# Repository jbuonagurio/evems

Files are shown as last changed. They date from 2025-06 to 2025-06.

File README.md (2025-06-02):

# Power Quality Analyzer

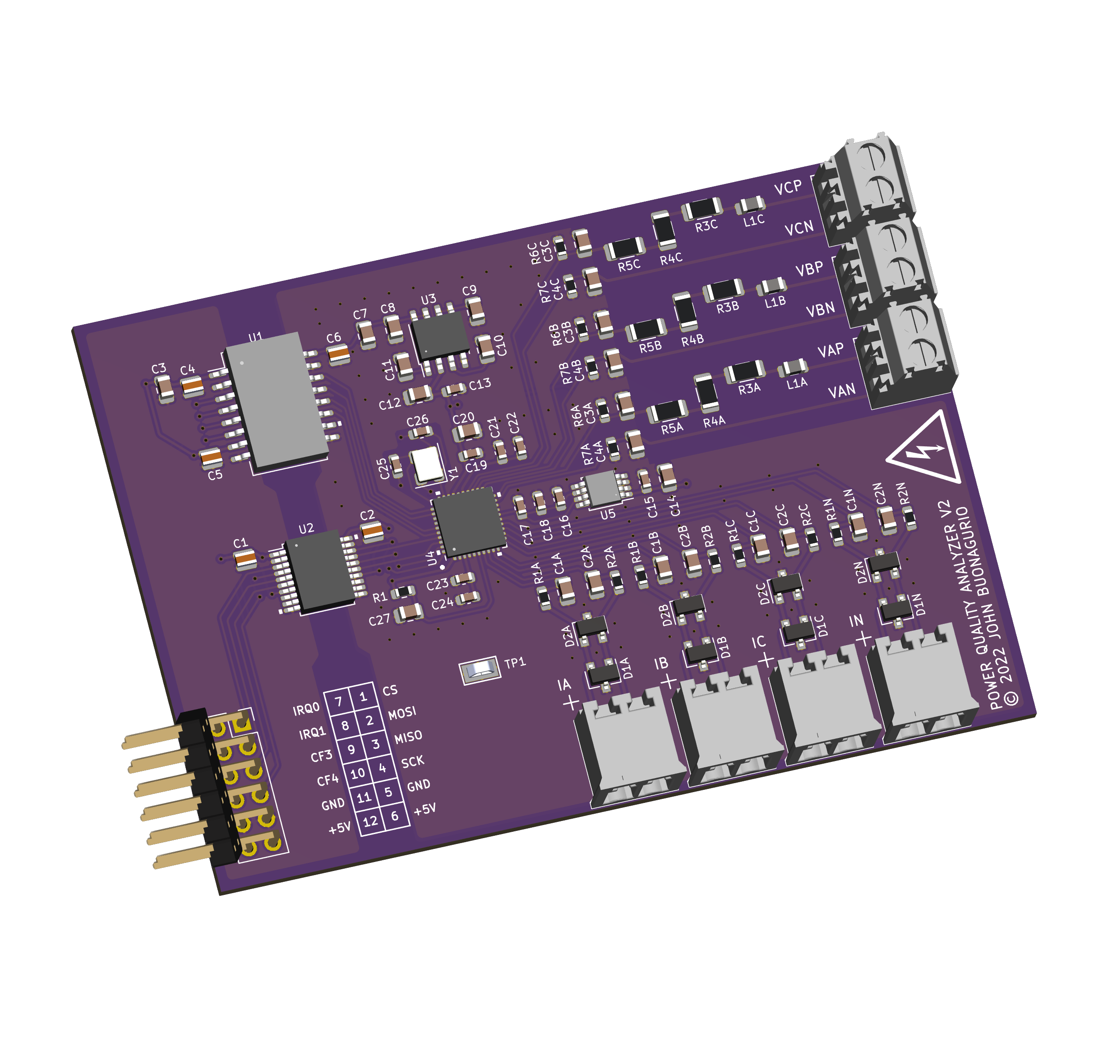
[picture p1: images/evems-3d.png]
3D View


## Schematic

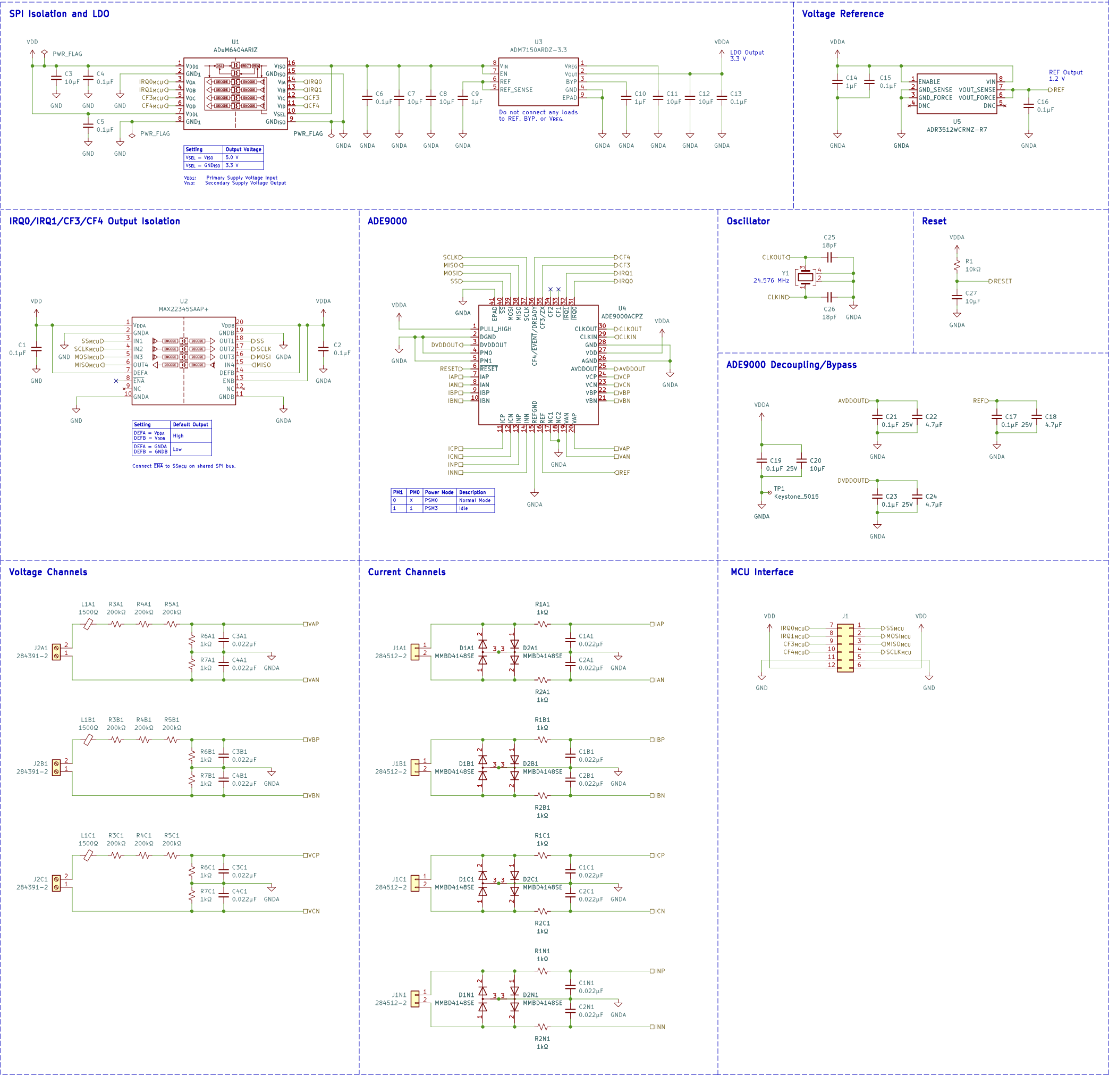
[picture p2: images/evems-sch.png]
Schematic


## Bill of Materials

| Designator | Quantity | Description | Manufacturer | Manufacturer Part Number | Digi-Key Part Number |
| :--- | :---: | :--- | :--- | :--- | :--- |
| C1 C2 C4 C5 C6 | 5 | Ceramic Capacitor 0.1 μF 25V X7R 0508 | KYOCERA AVX | 05083C104KAT2A | 478-12665-1-ND |
| C9 C10 C14 | 3 | Ceramic Capacitor 1 μF 35V X7R 0805 | KEMET | C0805C105K6RACTU | 399-15007-1-ND |
| C13 C15 C16 | 3 | Ceramic Capacitor 0.1 μF 10V X7R 0603 | KEMET | C0603C104K8RACTU | 399-C0603C104K8RAC7867CT-ND |
| C17 C19 C21 C23 | 4 | Ceramic Capacitor 0.1 μF 25V X8R 0603 | TDK Corporation | C1608X8R1E104K080AA | 445-2500-1-ND |
| C3 C7 C8 C11 C12  C20 C27 | 7 | Ceramic Capacitor 10 μF 25V X5R 0805 | KEMET | C0805C106K3PACTU | 399-11939-1-ND |
| C18 C22 C24 | 3 | Ceramic Capacitor 4.7 μF 10V X5R 0603 | KEMET | C0603C475K8PACTU | 399-C0603C475K8PAC7411CT-ND |
| C25 C26 | 2 | Ceramic Capacitor 18 pF 50V NP0 0603 | KEMET | CBR06C180J5GAC | 399-CBR06C180J5GACCT-ND |
| C1A C1B C1C C1N C2A  C2B C2C C2N C3A C3B C3C C4A C4B C4C | 14 | Ceramic Capacitor 0.022 μF 50V C0G 0805 | TDK Corporation | C2012C0G1H223J125AA | 445-7522-1-ND |
| D1A D1B D1C D1N D2A  D2B D2C D2N | 8 | Dual Switching Diode 100V 300mA SOT23 | Diodes Inc. | MMBD7000HS-7-F | MMBD7000HS-7FDICT-ND |
| J1 | 1 | Header 12 Position 0.100" (2.54mm) RA Through Hole | Samtec Inc. | TSW-106-08-L-D-RA | SAM1041-06-ND |
| J1A J1B J1C J1N | 4 | 2 Position Terminal Block 0.138" (3.50mm) RA Through Hole | TE Connectivity | 284512-2 | A98396-ND |
| J2A J2B J2C | 3 | 2 Position Terminal Block 0.138" (3.50mm) RA Through Hole | TE Connectivity | 284391-2 | A98159-ND |
| L1A L1B L1C | 3 | Ferrite Bead 1.5 kΩ @ 100 MHz 0805 250mA 450mΩ | Murata | BLM21BD152SN1D | 490-1048-1-ND |
| R1 | 1 | Resistor 10 kΩ ±1% 0.1W 0603 | Vishay Dale | CRCW060310K0FKEAC | 541-5136-1-ND |
| R1A R1B R1C R1N R2A  R2B R2C R2N R6A R6B R6C R7A R7B R7C | 14 | Resistor 1 kΩ ±0.1% 0.1W 0603 Thin Film | YAGEO | RT0603BRD071KL | YAG1237CT-ND |
| R3A R3B R3C R4A R4B  R4C R5A R5B R5C | 9 | Resistor 200 kΩ ±0.1% 0.25W 1206 Thin Film | Vishay Dale | TNPV1206200KBEEN | 541-4632-1-ND |
| TP1 | 1 | Test Point Miniature | Keystone Electronics | 5015 | 36-5015CT-ND |
| U1 | 1 | Digital Isolator 4 Channel 5000VRMS 16SOIC | Analog Devices Inc.  | ADUM6404ARIZ | 505-ADUM6404ARIZ-ND |
| U2 | 1 | Digital Isolator 4 Channel 3750VRMS 20SSOP | Maxim Integrated | MAX22345SAAP+ | 505-MAX22345SAAP+-ND |
| U3 | 1 | Linear Voltage Regulator 3.3V 800mA 8-SOIC-EP | Analog Devices Inc.  | ADM7150ARDZ-3.3 | 505-ADM7150ARDZ-3.3-ND |
| U4 | 1 | 7 Channel AFE 40-LFCSP-WQ | Analog Devices Inc.  | ADE9000ACPZ | 505-ADE9000ACPZ-ND |
| U5 | 1 | Voltage Reference 1.2V ±0.1% 10mA 8-MSOP | Analog Devices Inc.  | ADR3512WCRMZ-R7 | ADR3512WCRMZ-R7CT-ND |
| Y1 | 1 | Crystal 24.576 MHz ±20ppm 12pF 40Ω 4-SMD | ECS | ECS-245.7-12-33Q-JES-TR  | XC2178CT-ND |

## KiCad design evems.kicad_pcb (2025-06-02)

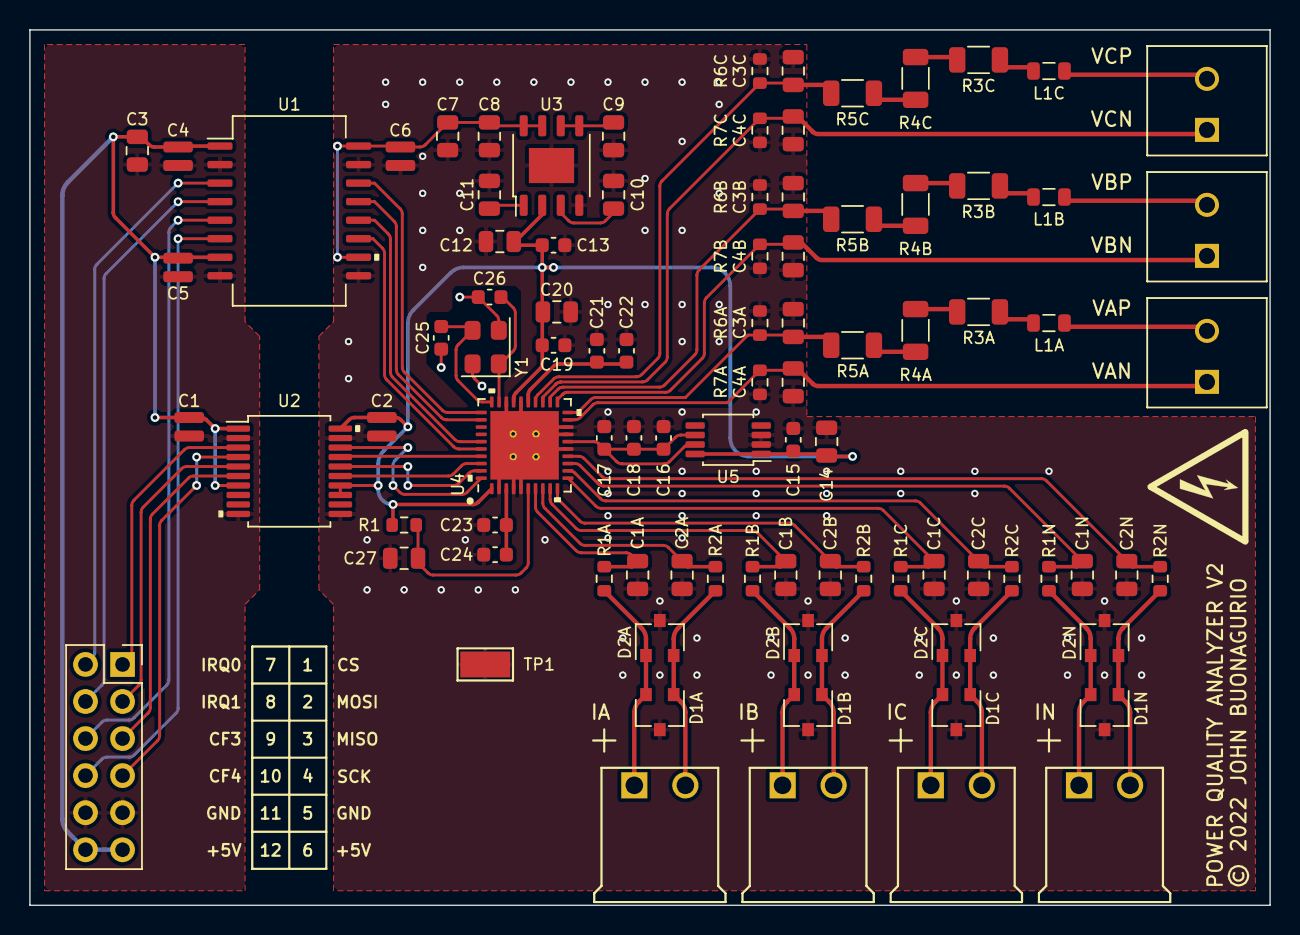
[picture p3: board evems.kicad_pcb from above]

Board: 2 copper layers, 85.0 x 60.0 mm, 91 parts (0 on the bottom side), 64 nets.

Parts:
C1, C2, C4, C5, C6: 0.1µF; C_0508_1220Metric
C1A1, C1B1, C1C1, C1N1, C2A1, C2B1, C2C1, C2N1, C3A1, C3B1, C3C1, C4A1, C4B1, C4C1: 0.022µF; C_0805_2012Metric
C3, C7, C8, C11, C12, C20, C27: 10µF; C_0805_2012Metric
C9, C10, C14: 1µF; C_0805_2012Metric
C13, C15, C16: 0.1µF; C_0603_1608Metric
C17, C19, C21, C23: 0.1µF 25V; C_0603_1608Metric
C18, C22, C24: 4.7µF; C_0603_1608Metric
C25, C26: 18pF; C_0603_1608Metric
D1A1, D1B1, D1C1, D1N1, D2A1, D2B1, D2C1, D2N1: MMBD4148SE; SC-59
J1: Conn_02x06_Top_Bottom; PinHeader_2x06_Pmod
J1A1, J1B1, J1C1, J1N1: 284512-2; TE_284512-2
J2A1, J2B1, J2C1: 284391-2; TE_284391-2
L1A1, L1B1, L1C1: 1500Ω; L_0805_2012Metric
R1: 10kΩ; R_0603_1608Metric
R1A1, R1B1, R1C1, R1N1, R2A1, R2B1, R2C1, R2N1, R6A1, R6B1, R6C1, R7A1, R7B1, R7C1: 1kΩ; R_0603_1608Metric
R3A1, R3B1, R3C1, R4A1, R4B1, R4C1, R5A1, R5B1, R5C1: 200kΩ; R_1206_3216Metric
TP1: Keystone_5015
U1: ADuM6404ARIZ
U2: MAX22345SAAP+
U3: ADM7150ARDZ-3.3
U4: ADE9000ACPZ
U5: ADR3512WCRMZ-R7
Y1: ECS-245.7-12-33Q-JES-TR

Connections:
/AVDDOUT: C21.1, C22.1, U4.25 (AVDDOUT)
/CF3: U1.12 (V_{IC}), U4.35 (CF3/ZX)
/CF3_{MCU}: J1.9, U1.5 (V_{OC})
/CF4: U1.11 (V_{ID}), U4.36 (CF4/~EVENT/DREADY)
/CF4_{MCU}: J1.10, U1.6 (V_{OD})
/CLKIN: C26.1, U4.29 (CLKIN), Y1.1
/CLKOUT: C25.1, U4.30 (CLKOUT), Y1.3
/DVDDOUT: C23.1, C24.1, U4.3 (DVDDOUT)
/IAN: C2A1.2, R2A1.1, U4.8 (IAN)
/IAP: C1A1.1, R1A1.1, U4.7 (IAP)
/IBN: C2B1.2, R2B1.1, U4.10 (IBN)
/IBP: C1B1.1, R1B1.1, U4.9 (IBP)
/ICN: C2C1.2, R2C1.1, U4.12 (ICN)
/ICP: C1C1.1, R1C1.1, U4.11 (ICP)
/INN: C2N1.2, R2N1.1, U4.14 (INN)
/INP: C1N1.1, R1N1.1, U4.13 (INP)
/IRQ0: U1.14 (V_{IA}), U4.31 (~IRQ0)
/IRQ0_{MCU}: J1.7, U1.3 (V_{OA})
/IRQ1: U1.13 (V_{IB}), U4.32 (~IRQ1)
/IRQ1_{MCU}: J1.8, U1.4 (V_{OB})
/MISO: U2.15 (IN4), U4.38 (MISO)
/MISO_{MCU}: J1.3, U2.6 (OUT4)
/MOSI: U2.16 (OUT3), U4.39 (MOSI)
/MOSI_{MCU}: J1.2, U2.5 (IN3)
/REF: C16.1, C17.1, C18.1, U4.16 (REF), U5.6 (VOUT_FORCE), U5.7 (VOUT_SENSE)
/RESET: C27.1, R1.1, U4.6 (~RESET)
/SCLK: U2.17 (OUT2), U4.37 (SCLK)
/SCLK_{MCU}: J1.4, U2.4 (IN2)
/SS: U2.18 (OUT1), U4.40 (~SS)
/SS_{MCU}: J1.1, U2.3 (IN1)
/VAN: C4A1.2, J2A1.1, R7A1.1, U4.19 (VAN)
/VAP: C3A1.1, R5A1.1, R6A1.2, U4.20 (VAP)
/VBN: C4B1.2, J2B1.1, R7B1.1, U4.21 (VBN)
/VBP: C3B1.1, R5B1.1, R6B1.2, U4.22 (VBP)
/VCN: C4C1.2, J2C1.1, R7C1.1, U4.23 (VCN)
/VCP: C3C1.1, R5C1.1, R6C1.2, U4.24 (VCP)
GND: C1.2, C3.2, C4.2, C5.2, J1.5, J1.11, U1.2 (GND_{1}), U1.8 (GND_{1}), U2.2 (GNDA), U2.10 (GNDA)
GNDA: C1A1.2, C1B1.2, C1C1.2, C1N1.2, C2.2, C2A1.1, C2B1.1, C2C1.1, C2N1.1, C3A1.2, C3B1.2, C3C1.2, C4A1.1, C4B1.1, C4C1.1, C6.2, C7.2, C8.2, C9.2, C10.1, C11.1, C12.1, C13.1, C14.2, C15.2, C16.2, C17.2, C18.2, C19.2, C20.2, C21.2, C22.2, C23.2, C24.2, C25.2, C26.2, C27.2, D1A1.3 (common), D1B1.3 (common), D1C1.3 (common), D1N1.3 (common), D2A1.3 (common), D2B1.3 (common), D2C1.3 (common), D2N1.3 (common), R6A1.1, R6B1.1, R6C1.1, R7A1.2, R7B1.2, R7C1.2, TP1.1, U1.9 (GND_{ISO}), U1.15 (GND_{ISO}), U2.11 (GNDB), U2.19 (GNDB), U3.4 (GND), U3.9 (EPAD), U4.2 (DGND), U4.4 (PM0), U4.5 (PM1), U4.15 (REFGND), U4.17 (NC1), U4.18 (NC2), U4.26 (AGND), U4.28 (GND), U4.41 (EPAD), U5.2 (GND_SENSE), U5.3 (GND_FORCE), Y1.2, Y1.4
unnamed: C6.1, C7.1, C8.1, U1.10 (V_{SEL}), U1.16 (V_{ISO}), U3.7 (EN), U3.8 (V_{IN})
unnamed: C9.1, U3.5 (REF_SENSE), U3.6 (REF)
unnamed: C10.2, U3.3 (BYP)
unnamed: C11.2, U3.1 (V_{REG})
unnamed: D1A1.1 (A), D2A1.2 (K), J1A1.2, R2A1.2
unnamed: D1A1.2 (K), D2A1.1 (A), J1A1.1, R1A1.2
unnamed: D1B1.1 (A), D2B1.2 (K), J1B1.2, R2B1.2
unnamed: D1B1.2 (K), D2B1.1 (A), J1B1.1, R1B1.2
unnamed: D1C1.1 (A), D2C1.2 (K), J1C1.2, R2C1.2
unnamed: D1C1.2 (K), D2C1.1 (A), J1C1.1, R1C1.2
unnamed: D1N1.1 (A), D2N1.2 (K), J1N1.2, R2N1.2
unnamed: D1N1.2 (K), D2N1.1 (A), J1N1.1, R1N1.2
unnamed: J2A1.2, L1A1.2
unnamed: J2B1.2, L1B1.2
unnamed: J2C1.2, L1C1.2
unnamed: L1A1.1, R3A1.2
unnamed: L1B1.1, R3B1.2
unnamed: L1C1.1, R3C1.2
unnamed: R3A1.1, R4A1.2
unnamed: R3B1.1, R4B1.2
unnamed: R3C1.1, R4C1.2
unnamed: R4A1.1, R5A1.2
unnamed: R4B1.1, R5B1.2
unnamed: R4C1.1, R5C1.2
VDD: C1.1, C3.1, C4.1, C5.1, J1.6, J1.12, U1.1 (V_{DD1}), U1.7 (V_{DDL}), U2.1 (V_{DDA}), U2.7 (DEFA)
VDDA: C2.1, C12.2, C13.2, C14.1, C15.1, C19.1, C20.1, R1.2, U2.13 (ENB), U2.14 (DEFB), U2.20 (V_{DDB}), U3.2 (V_{OUT}), U4.1 (PULL_HIGH), U4.27 (VDD), U5.1 (ENABLE), U5.8 (VIN)

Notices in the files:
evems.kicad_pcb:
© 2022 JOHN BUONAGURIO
